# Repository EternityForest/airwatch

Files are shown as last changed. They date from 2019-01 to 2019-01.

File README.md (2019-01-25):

# AirWatch: ESP8266 I2C/ADC/Battery board

#AS IS!!!!!
I've changed some stuff since actually building these. I'll write some proper docs eventually I suppose.
Mostly just gettingthis under VC.

## Features/Hacks used

* Somethinng is wrong with the 0805 footprints. The
* There's a ton of voltage  drop on the way to the battery. 
* It might only charge to 50% from 5v. Good enough, they don't like full charge anyway.
* WiFi Is Fussy! Or maybe it isn't? I'm testing with unfinished code.
* Totally untested fancy easy to solder bigger 0805 pads!

* You can't use the TX pin, it controls the battery charger
* Ok, maybe the world won't end if you send some stuff anyway?
* You can controll the charger!
* 5v-24v input.
* No onboard programming
* A button! It conflicts with the RX pin!
* A power switch! That actually disconnecxts the battery!
* A reliance on the load dump protectionof the LDO
* ^ to save it from the tiny reverse current in battery mode when filling the input cap
* An ADC(ADS1015 at 0x49, not the adafruit lib default)

* read the schematic
* a transistor as a standin for a reg I didn't have a footprint for
* The reg will probably overheat if you use it from more than 7v or so, unless you're always in sleep mode.
* Will probably not work at all if you use a cheaper LDO
* seriously read it

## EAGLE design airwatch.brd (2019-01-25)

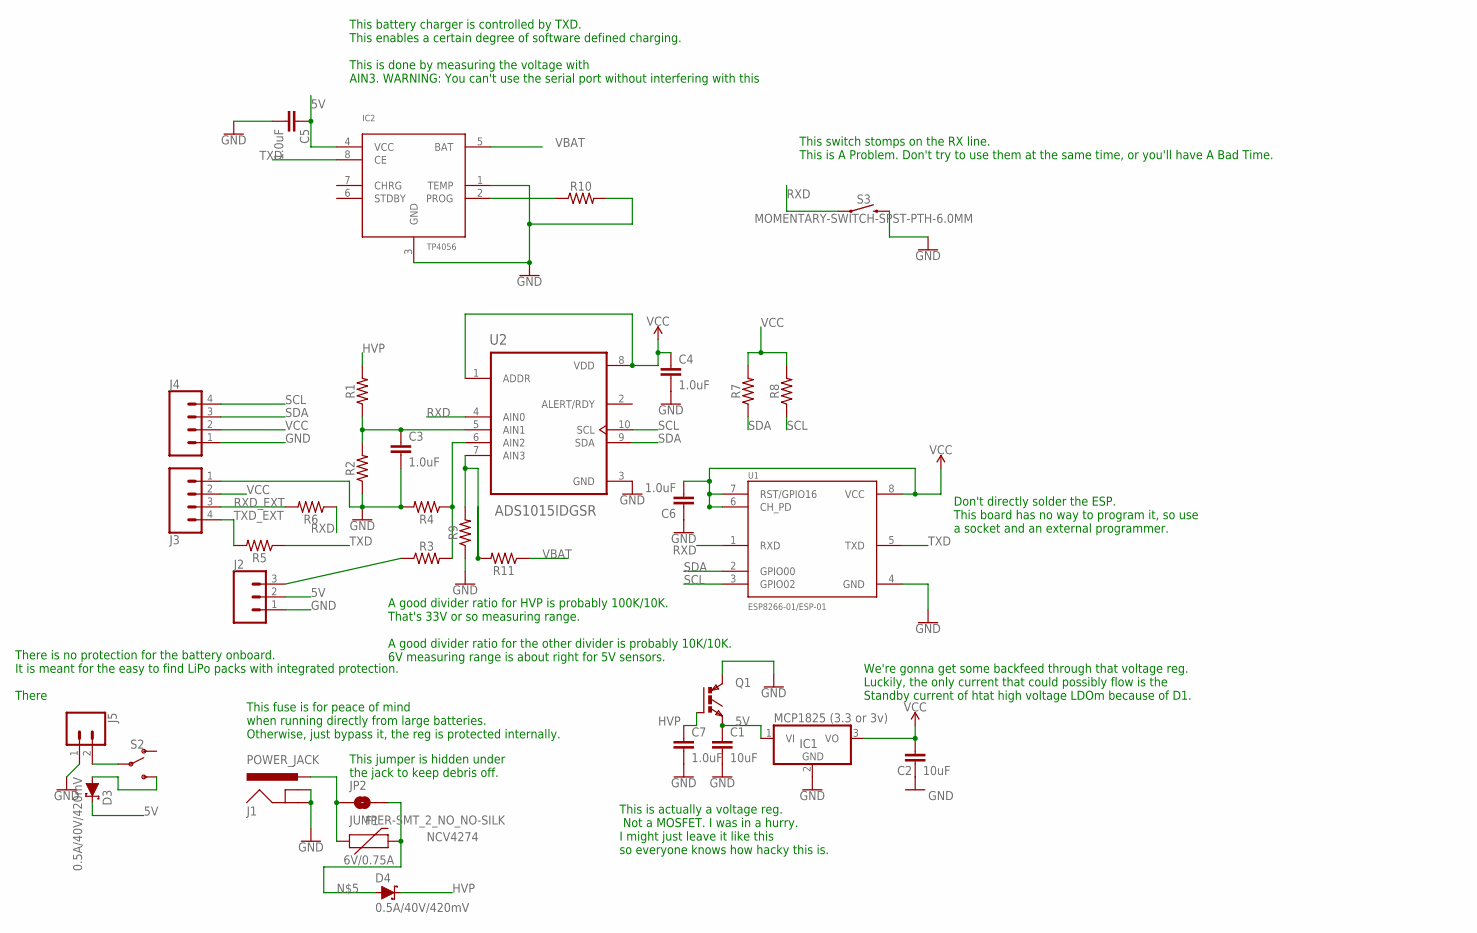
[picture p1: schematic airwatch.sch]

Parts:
C1, C2: 10uF; 0805
C3, C4, C5, C7: 1.0uF; 0805-EZ
C6: 1.0uF; 1206-EZ
D3, D4: 0.5A/40V/420mV; SOD-323
F1: 6V/0.75A; 1206
IC1: MCP1825 (3.3 or 3v); SOT223
IC2: TP4056; SOP-8
J1: POWER_JACK; POWER_JACK_PTH
J2: CONN_03JST-PTH-VERT; JST-3-PTH-VERT
J3, J4: CONN_04JST-PTH-VERT; JST-4-PTH-VERT
J5: CONN_02JST-PTH-2; JST-2-PTH
JP2: JUMPER-SMT_2_NO_NO-SILK; SMT-JUMPER_2_NO_NO-SILK
Q1: NCV4274; TO252_STM
R1, R2, R3, R4, R5, R6, R7, R8, R9, R10, R11: 0805-EZ
S2: SWITCH-SPDT-PTH-11.6X4.0MM-LOCK; SWITCH_SPDT_PTH_11.6X4.0MM_LOCK
S3: MOMENTARY-SWITCH-SPST-PTH-6.0MM; TACTILE_SWITCH_PTH_6.0MM
U1: ESP8266-01/ESP-01; XCVR_ESP8266-01/ESP-01
U2: ADS1015IDGSR; SOP50P490X110-10N

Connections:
5V: C1.1, C5.1, D3.C, IC1.1 (VI), IC2.4 (VCC), J2.2, Q1.3 (E)
GND: C1.2, C2.2, C3.2, C4.2, C5.2, C6.1, C7.2, IC1.2 (GND), IC2.1 (TEMP), IC2.3 (GND), J1.GND, J1.GNDBREAK, J2.1, J3.1, J4.1, J5.1, Q1.2 (C), R2.1, R4.2, R9.1, R10.2, S3.3 (2), U1.4 (GND), U2.3 (GND)
HVP: C7.1, D4.C, Q1.1 (G), R1.2
unnamed: J2.3, R3.1
unnamed: R3.2, R4.1, U2.6 (AIN2)
unnamed: R9.2, R11.2, U2.7 (AIN3)
unnamed: D4.A, F1.2, JP2.2
unnamed: C3.1, R1.1, R2.2, U2.5 (AIN1)
unnamed: F1.1, J1.PWR, JP2.1
unnamed: J5.2, S2.2
unnamed: IC2.2 (PROG), R10.1
RXD: R6.1, S3.1, U1.1 (RXD), U2.4 (AIN0)
RXD_EXT: J3.3, R6.2
SCL: J4.4, R8.1, U1.3 (GPIO02), U2.10 (SCL)
SDA: J4.3, R7.1, U1.2 (GPIO00), U2.9 (SDA)
TXD: IC2.8 (CE), R5.1, U1.5 (TXD)
TXD_EXT: J3.4, R5.2
VBAT: D3.A, IC2.5 (BAT), R11.1, S2.3 (S)
VCC: C2.1, C4.1, C6.2, IC1.3 (VO), J3.2, J4.2, R7.2, R8.2, U1.6 (CH_PD), U1.7 (RST/GPIO16), U1.8 (VCC), U2.1 (ADDR), U2.8 (VDD)

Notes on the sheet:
This is actually a voltage reg. Not a MOSFET. I was in a hurry. I might just leave it like this so everyone knows how hacky this is.
Don't directly solder the ESP. This board has no way to program it, so use a socket and an external programmer.
This switch stomps on the RX line. This is A Problem. Don't try to use them at the same time, or you'll have A Bad Time.
A good divider ratio for HVP is probably 100K/10K. That's 33V or so measuring range. A good divider ratio for the other divider is probably 10K/10K. 6V measuring range is about right for 5V sensors.
We're gonna get some backfeed through that voltage reg. Luckily, the only current that could possibly flow is the Standby current of htat high voltage LDOm because of D1.
This fuse is for peace of mind when running directly from large batteries. Otherwise, just bypass it, the reg is protected internally.
This jumper is hidden under the jack to keep debris off.
This battery charger is controlled by TXD. This enables a certain degree of software defined charging. This is done by measuring the voltage with AIN3. WARNING: You can't use the serial port without interfering with this
There is no protection for the battery onboard. It is meant for the easy to find LiPo packs with integrated protection. There

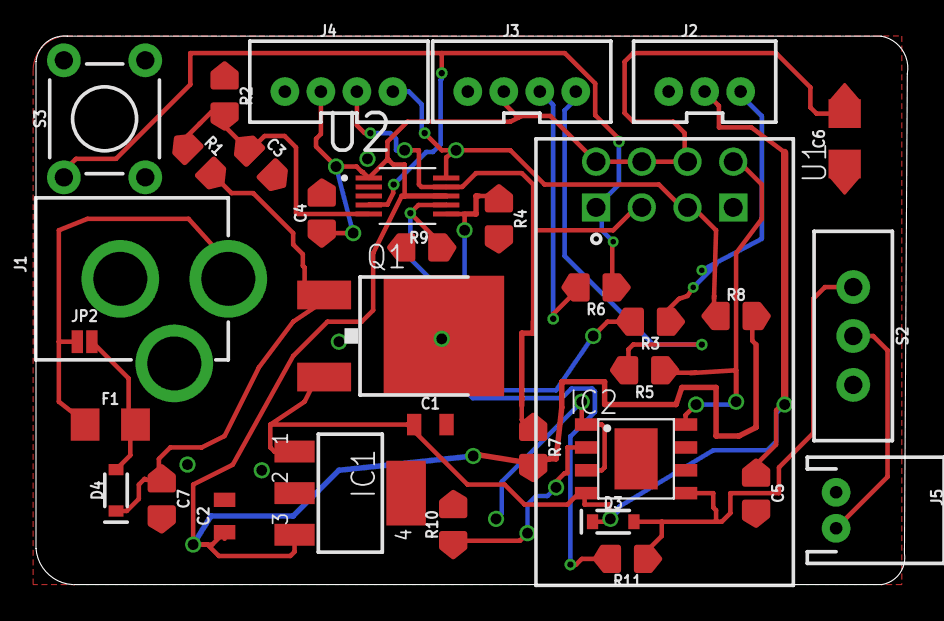
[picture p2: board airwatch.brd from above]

Board: 2 copper layers, 48.4 x 30.5 mm, 34 parts (0 on the bottom side), 19 nets.

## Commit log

2019-01-25 First super hacky barely tested commit
    [airwatch.brd, airwatch.sch]
2019-01-25 Soldermask for the 0805-ez pads. Totally untested, might even revert.
    [airwatch.brd, airwatch.sch]

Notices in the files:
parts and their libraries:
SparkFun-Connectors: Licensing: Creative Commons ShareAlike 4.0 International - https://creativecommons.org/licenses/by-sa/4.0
